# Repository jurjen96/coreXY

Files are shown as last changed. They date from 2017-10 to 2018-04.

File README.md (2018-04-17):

# Introduction

This repository will describe the process of designing and building an open
source 3D printer designed in Autodesk Inventor 2018. I am aware that Autodesk
Inventor is not open source, but when the first version is ready, I will put
STEP files in this repo so that everyone can edit the files.

**Some specs:**
 -  Print volume: 210x200x300 mm
 -  Frame size: 390x400x500 mm

# Planning

 -  ~~Design initial 3D design~~
 -  ~~Build the printer~~
 -  Test the printer
 -  Redesign parts and upgrade the printer
 -  Implement a Raspberry Pi
 -  Implement speech recognition, so that the printer can be controlled by voice

# Current status

The printer is put together and is producing already usable results (example
can be found [here](#printResult)). The next step is to redesign the x-carriage
because it is still not easy to attach the belts to it. Also, all the black belts
will be replaced with belts with metal in it to add more rigidity to the printer.

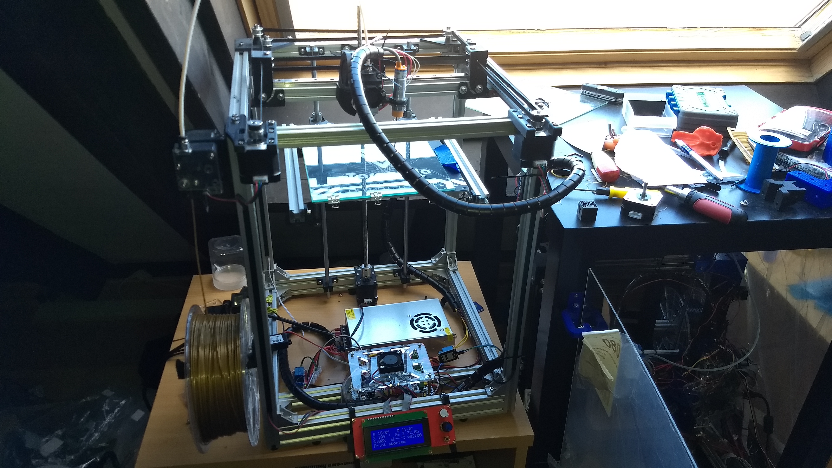
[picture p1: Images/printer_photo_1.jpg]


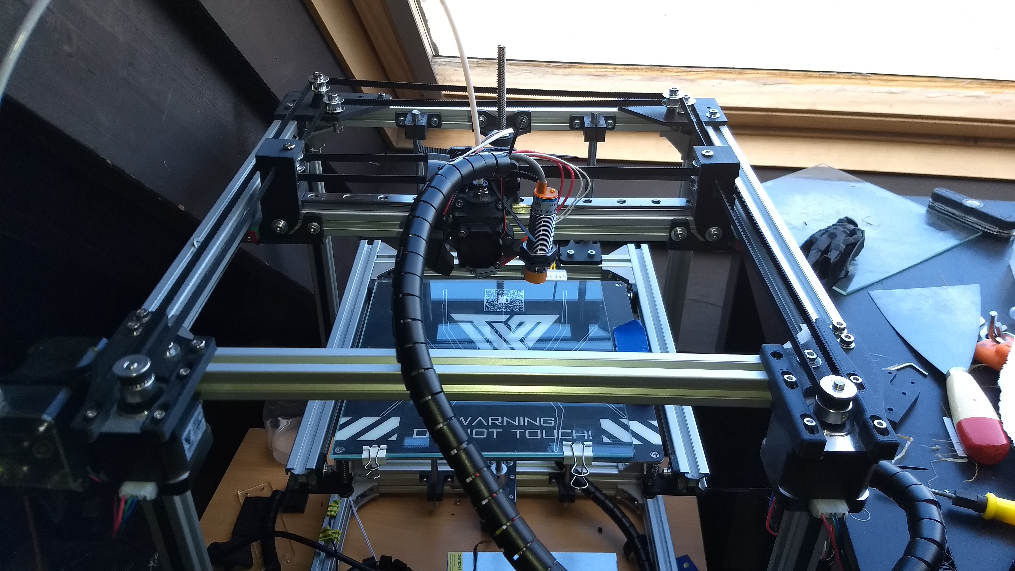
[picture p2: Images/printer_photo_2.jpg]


## Render of design:

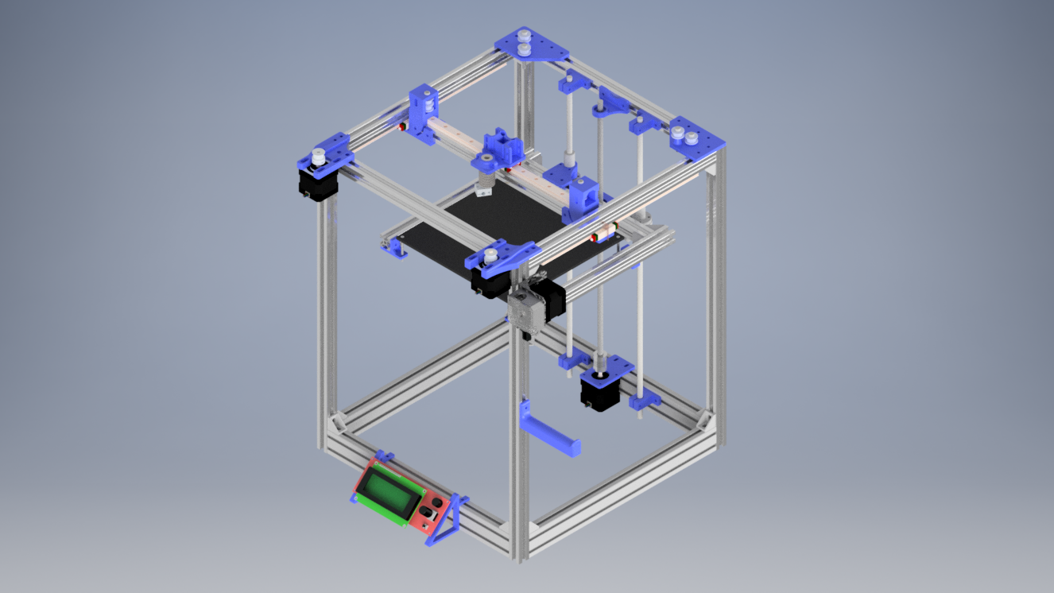
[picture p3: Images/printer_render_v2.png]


##  Print results:

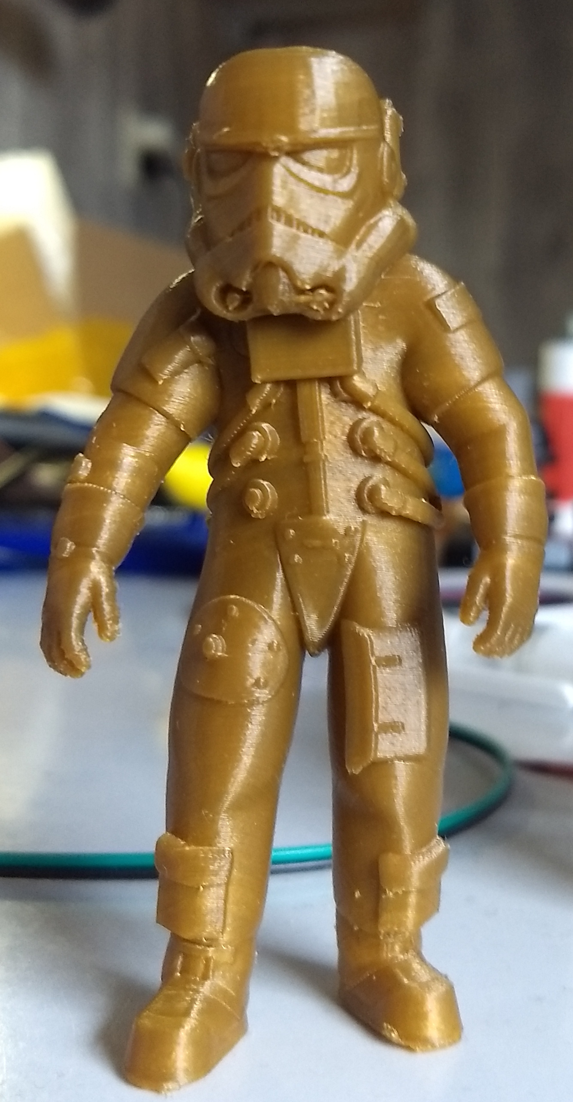
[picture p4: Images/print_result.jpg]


# Credits:

 -  **JuanCR**: [E3DV6 hotend](https://grabcad.com/library/e3dv6-hotend-1-75mm-1 "Grabcad E3DV6")
 -  **Ben Neubauer**: [E3D titan extruder](https://grabcad.com/library/e3d-titan-extruder-2 "Grabcad E3D titan extruder")
 -  **Lehaiver**: [NEMA 17](https://grabcad.com/library/nema-17-40mm-stepper-motor-1 "Grabcad nema 17")
 -  **Tom Edwards**: [Shaft coupler](https://grabcad.com/library/shaft-coupler-5-x-8-x-25mm-1 "Grabcad shaft coupler")
 -  **Jori Mäkinen**: [Linear guide mgn12](https://grabcad.com/library/linear-guide-mgn12-1 "Grabcad linear guide")
 -  **Ryan**: [MGN 12h linear guide](https://grabcad.com/library/hiwin-mgn-12h-linear-guide-1 "Grabcad mgn 12h")
 -  **Paulo Santos**: [GT2 pulley](https://grabcad.com/library/polia-gt2-20-dentes-com-rolamento-gt2-pulley-with-bearing-1 "Grabcad GT2 pulley")
 -  **Motedis**: [2020 extrusion](http://www.motedis.nl/shop/table_cats.php?table_id=16 "Motedis 2020 extrusion")  
 -  **Jacob**: [2004 LCD](https://grabcad.com/library/ramps-2004-lcd-prusa-reprap-screen-1-4-1 "Grabcad 2004 LCD")

This projects makes use of the Marlin firmware which is published under the
GPLv3 license. More information about the Marlin firmware  can be found
[here](http://marlinfw.org/). 

**Notice: This is a work in progress. Use at your own risk!**

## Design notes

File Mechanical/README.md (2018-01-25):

# BOM (**not final**)

Mechanical:
 -  1x E3DV6 (clone)
 -  1x Tevo titan extruder
 -  2020 aluminium extrusion:
    *  4x 500 mm 
    *  4x 350 mm 
    *  6x 320 mm
    *  2x 290 mm
    *  1x 240 mm
 -  2040 aluminium extrusion:
    *  2x 350 mm
 -  1x PTFE tube 1m
 -  1x 430 mm leadscrew
 -  2x 500 mm chrome plated rod
 -  2x LMF8LUU
 -  8x GT2 Idler 20 Teeth Pulley 5 mm bore
 -  2x GT2 20 Teeth Pulley 5mm shaft
 -  1x GT2-6mm Belt 5 m
 -  50x M4 T-nut
 -  1x Borosilicate Glass Plate 213x200x3mm 

Electrical:
 -  4x NEMA17
 -  1x 12v Heat bed 220x220 mm
 -  1x MKS Base v1.4
 -  1x 12V 40w Cartridge heater 
 -  1x NTC 3950 100K ohm 
 -  4x Endstops
 -  1x 12 AWG 1 m RED
 -  1x 12 AWG 1 m BLACK
 -  1x Power supply 220v to 12v

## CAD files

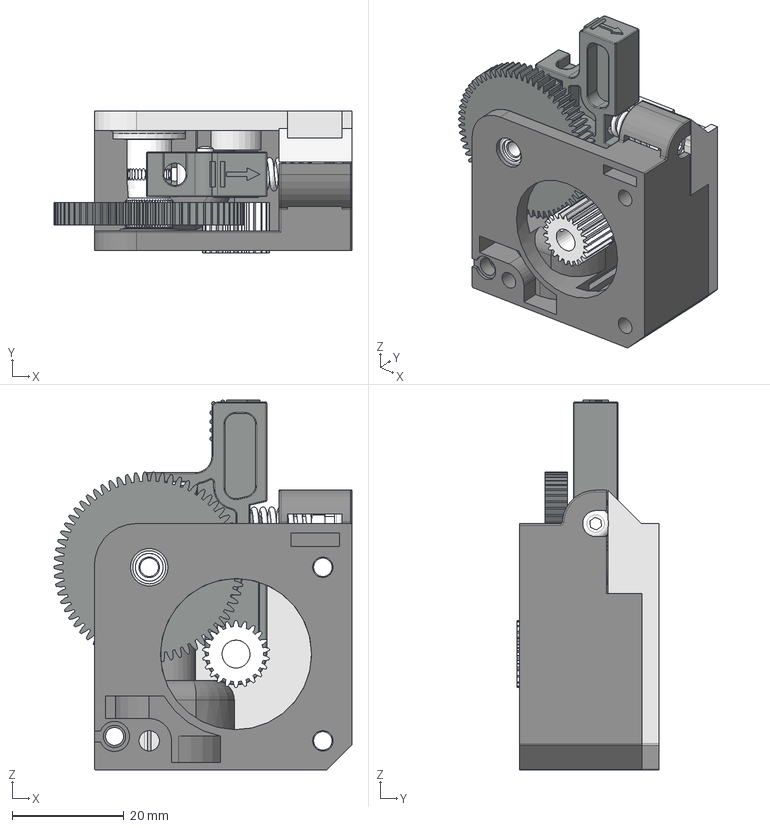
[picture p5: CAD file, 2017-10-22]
Mechanical/extruder/e3d titan.stp
53.2 x 25.3 x 66.1 mm
Base
9x5x3mm bearing x 2
hobbed wheel
filament gear
motor gear
cover
m3x8
M3 nut
idler spring
tensioner
idler bearing pin
idler bearing
guide tube

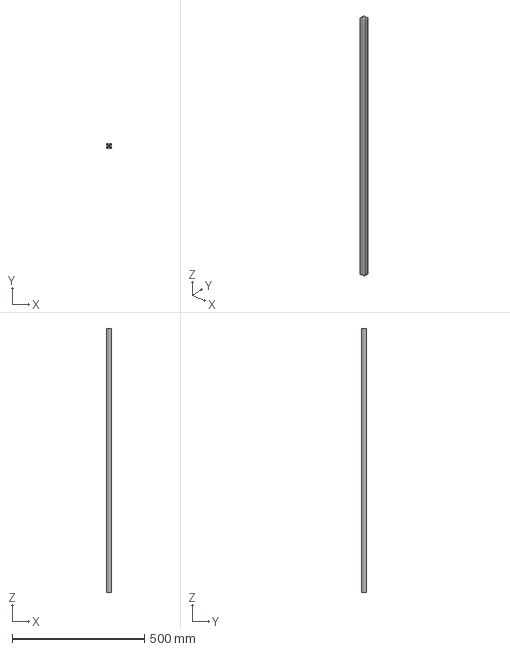
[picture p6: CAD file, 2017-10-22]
Mechanical/motedis/P20_N5_I.stp
20.0 x 20.0 x 1000.0 mm

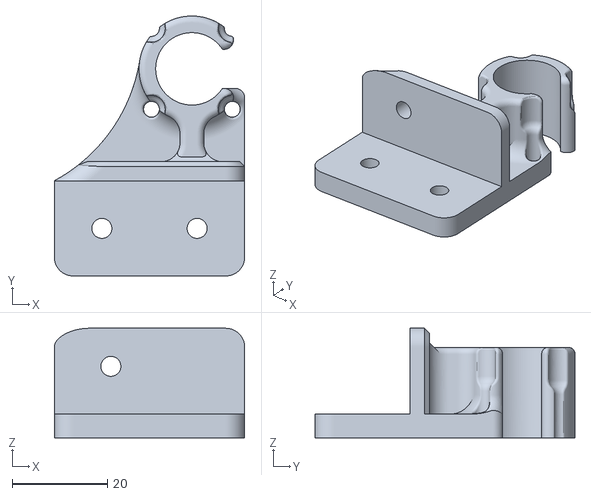
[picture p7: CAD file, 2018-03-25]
Mechanical/Printable Files/reinforcement-z-axis-LMF8LUU.stl
40.0 x 54.6 x 23.0

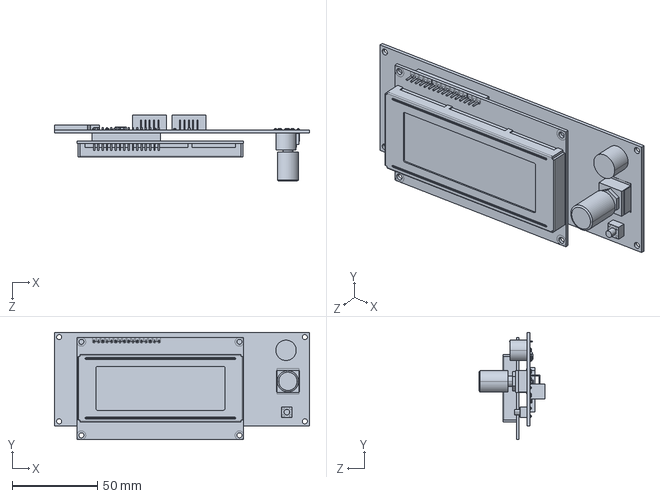
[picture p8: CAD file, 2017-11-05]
Mechanical/Ramps 1.4 2004 LCD PRUSA RepRap.STEP
150.0 x 63.0 x 38.9 mm

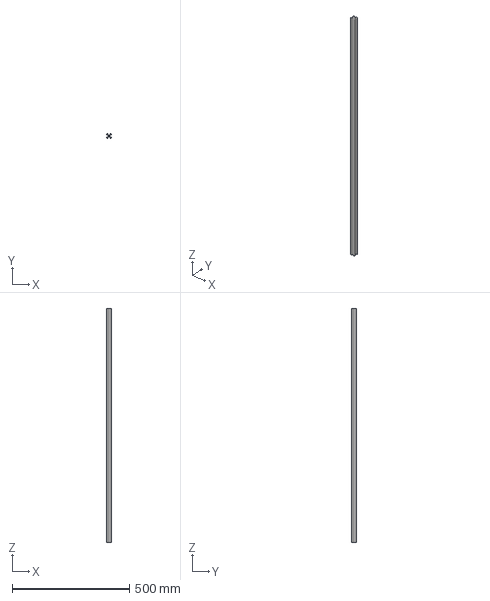
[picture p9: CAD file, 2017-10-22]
Mechanical/motedis/P20_N6_B.stp
20.0 x 20.0 x 1000.0 mm

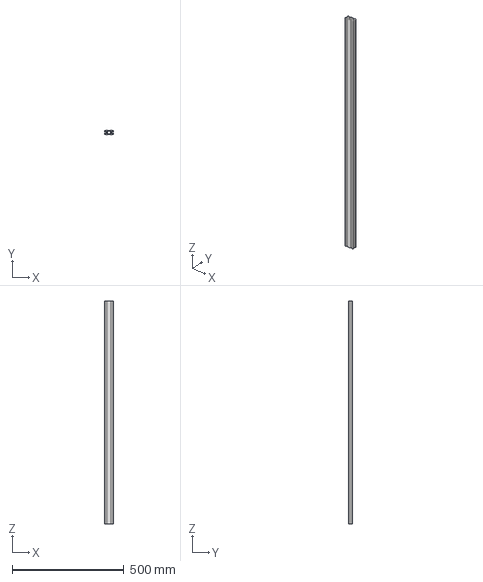
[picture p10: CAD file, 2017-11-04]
Mechanical/P20x40_N5_I.stp
40.0 x 20.0 x 1000.0 mm

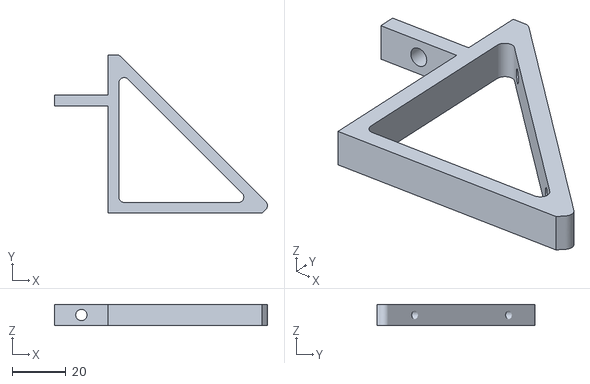
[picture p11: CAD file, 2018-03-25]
Mechanical/Printable Files/holder-LCD-v2.stl
79.3 x 59.0 x 8.00

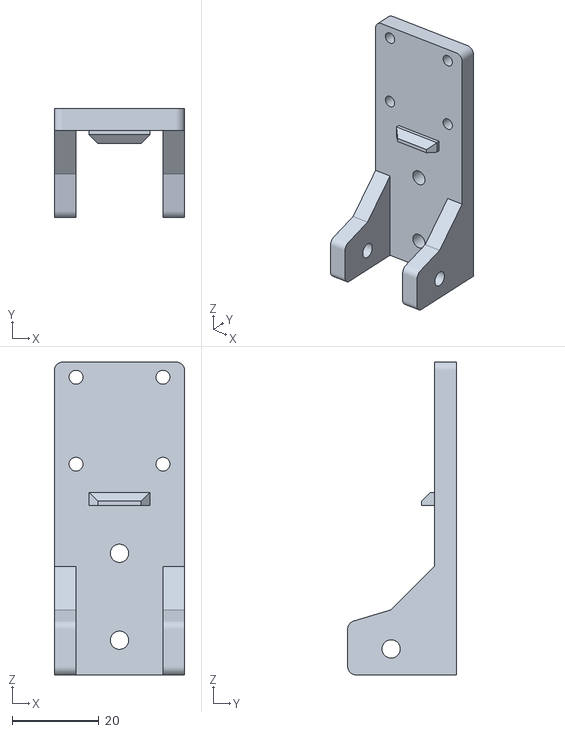
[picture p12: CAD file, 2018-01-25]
Mechanical/Printable Files/X-connector-left.stl
30.0 x 25.0 x 72.0

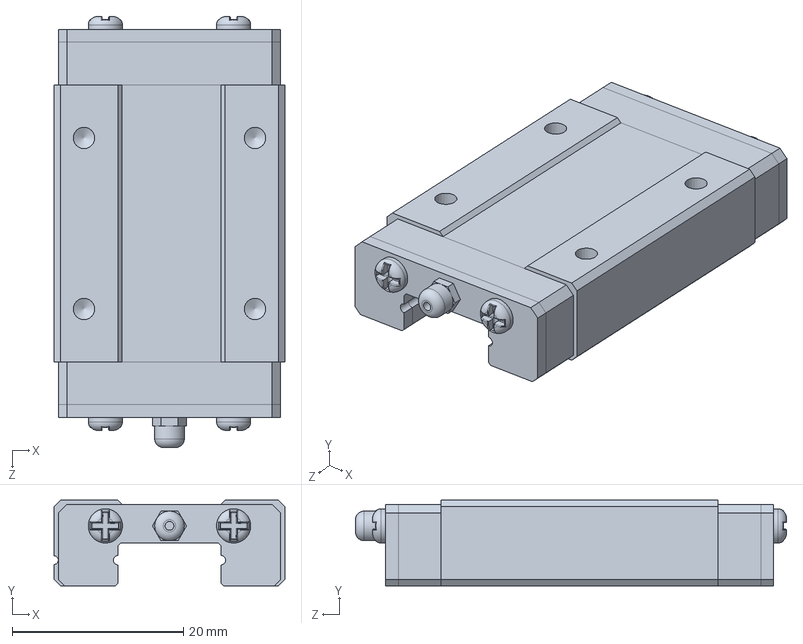
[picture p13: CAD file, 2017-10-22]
Mechanical/MGN_12_H_CARRAGE.SLDPRT
27.0 x 10.0 x 50.4 mm

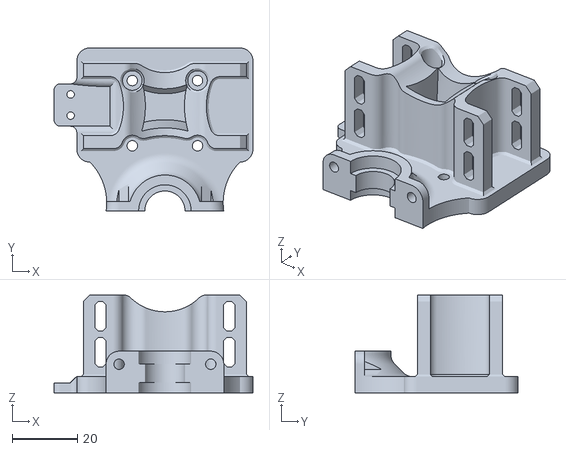
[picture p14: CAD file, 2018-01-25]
Mechanical/Printable Files/x-carriage.stl
61.0 x 50.0 x 30.0

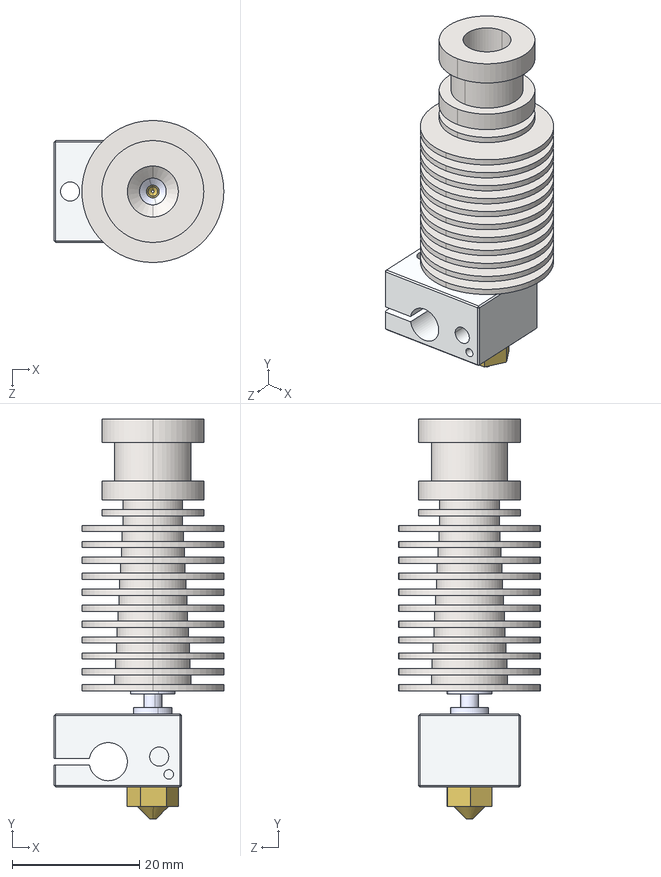
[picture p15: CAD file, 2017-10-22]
Mechanical/ED3V6.STEP
26.7 x 62.8 x 22.3 mm
HEATSINK
NOZZLE 0.4
HEATBRICK
HEATERBLOCK

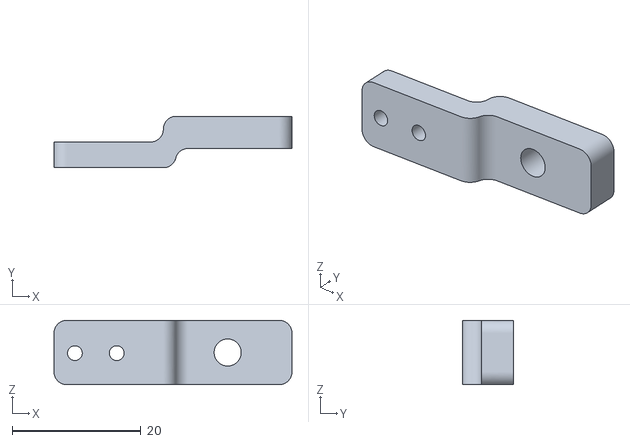
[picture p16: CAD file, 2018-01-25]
Mechanical/Printable Files/y-endstop-bracket.stl
37.0 x 8.00 x 10.0

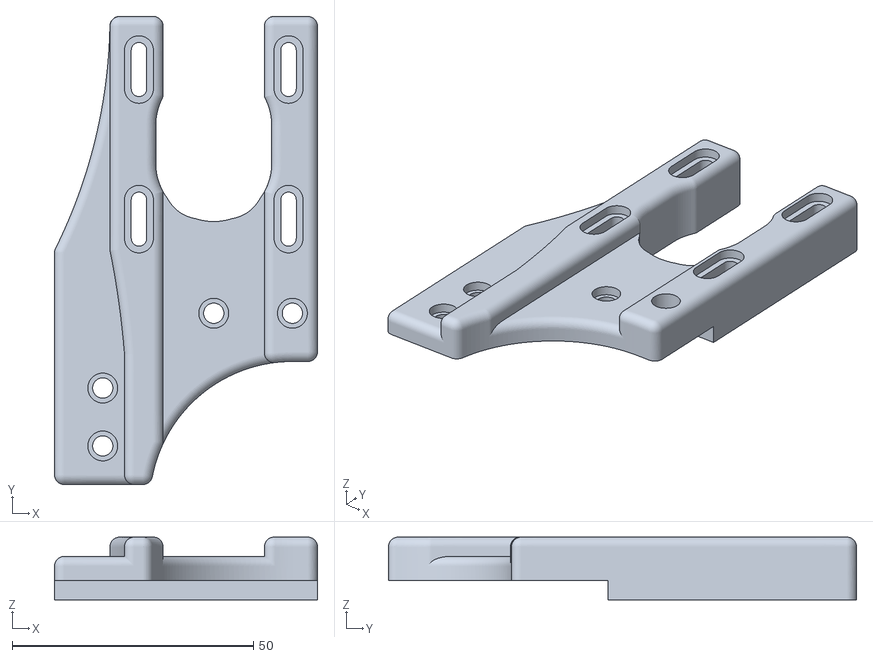
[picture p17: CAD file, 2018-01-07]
Mechanical/Printable Files/nema17-mount-right.stl
54.5 x 97.0 x 13.0

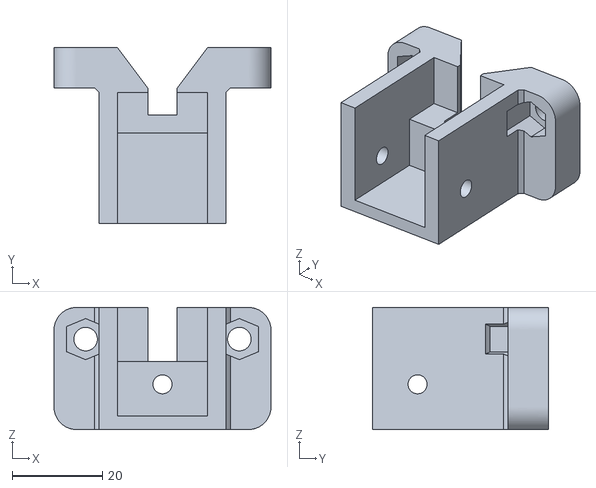
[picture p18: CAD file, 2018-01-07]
Mechanical/Printable Files/holder-GT2-x-carriage-right.stl
48.0 x 39.0 x 27.0

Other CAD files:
Mechanical/Printable Files/X-connector-right.stl
Mechanical/Printable Files/holder-LCD-screen.stl
Mechanical/Printable Files/holder-GT2-x-carriage-left.stl
Mechanical/Printable Files/holder-LMF8LUU-z-axis-v2.stl
Mechanical/00953 - Lineaarijohde MGN 12.SLDPRT
Mechanical/2020-240mm.ipt
Mechanical/2020-260mm.ipt
Mechanical/2020-290mm.ipt
Mechanical/2020-320mm.ipt
Mechanical/2020-350mm.ipt
Mechanical/2020-500mm.ipt
Mechanical/2020-corner-bracket.ipt
Mechanical/2040-350mm.ipt
Mechanical/2040-360mm.ipt
Mechanical/AssemblyFullPrinter.iam
Mechanical/ED3V6.ipt
Mechanical/GT2_Holder.ipt
Mechanical/LMF8LUU.ipt
Mechanical/M3x40mm.ipt
Mechanical/M5-nut.ipt
Mechanical/M5x30mm.ipt
Mechanical/M5x35mm-crosshead.ipt
Mechanical/M5x35mm.ipt
Mechanical/M5x40mm.ipt
Mechanical/MGN-12-H-carriage.ipt
Mechanical/MGN-12-rail.ipt
Mechanical/MotorMount1.ipt
Mechanical/MotorMount1_MIR.ipt
Mechanical/MotorMount2.ipt
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

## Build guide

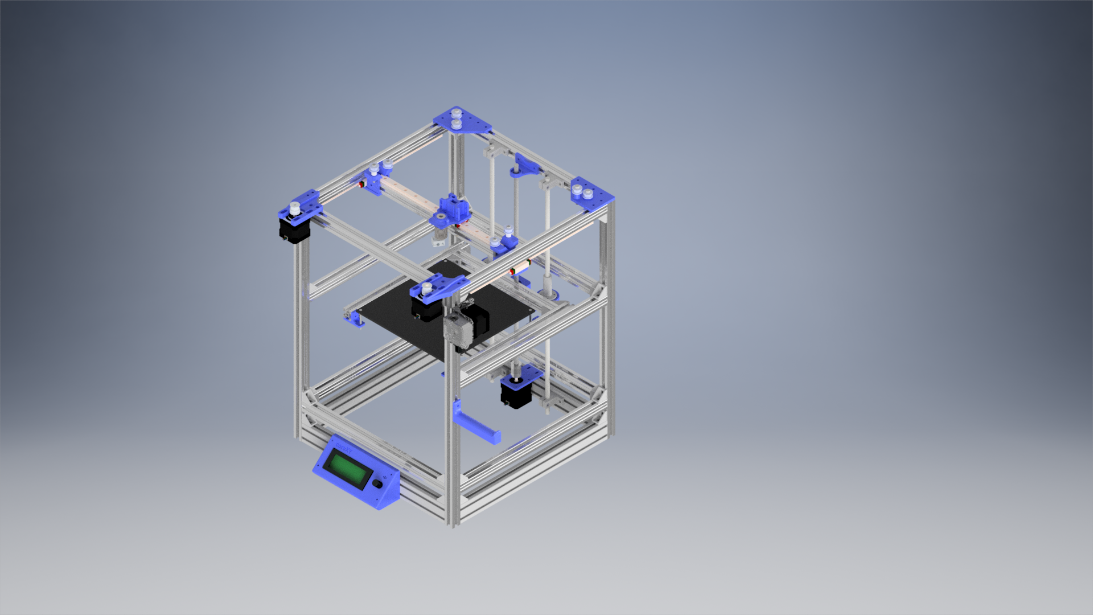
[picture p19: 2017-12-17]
Images/printer_render_v1.png

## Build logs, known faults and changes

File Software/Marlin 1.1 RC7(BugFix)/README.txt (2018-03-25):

This is the Marlin v1.1 Release Candidate Bugfix firmware as of August 9, 2016.

+++++++++++++++++++++++++++++++++++++++++++++++++++++++++++++++++++++++++++++++++++++++++++++++++++++++++++++++++++++
+ IMPORTANT! There are two configuration.h files provided. One with Auto Bed Leveling enabled and one with Auto Bed +
+ Leveling disabled. YOU MUST COPY THE APPROPRIATE CONFIGURATION.H FILE INTO THE MARLIN FOLDER.                     +
+++++++++++++++++++++++++++++++++++++++++++++++++++++++++++++++++++++++++++++++++++++++++++++++++++++++++++++++++++++

Hot end and heated bed PID is enabled, you should run PID autotune.

The configuration.h file with auto bed levelling has been configured for the TEVO Tarantula with a fixed sensor.

This release includes support for multiple extruders. It is not enabled as I can't test this feature.

This release includes support for BLTouch sensor. I don't have one, so can't test. See line 461.

You can now change the LCD controller encoder (knob) direction for menus and for values separately, in configuration.h. See lines 1035 to 1058.

A new feature has been added: Print statistics are now saved. The statistics can be read out with M78 command. (Verbose mode may need to be enabled in your host program.) See lines 930 to 939 in configuration.h

Don't forget to send M502 followed by M500 after uploading to update EEPROM settings!

Use at your own risk!

You will need to modify several settings in configuration.h for your specific printer:

Lines 588 to 591: Set your axis directions. They are currently set to match the build in Ed's videos. Should be fine for most, but some may need to change Y axis direction.

Lines 618 to 624: Set your bed dimensions. (For large bed option, change line 507 to "#define Y_MAX_POS 280")

Lines 731 to 735: Set your home position offsets. See How to set home position offsets below.

Note that EEPROM is enabled. If you do not wish to use EEPROM, comment out line 798.

Lines 489 to 491: If you are using a Z-Probe, set your offsets here. You can leave the Z offset at 0, see comments about M851 below.

If you are using Auto Bed Levelling and you have a fixed sensor attached to the hot end, you should be good to go (after making the changes described above. If you have some other kind of sensor (servo type, sled, etc) read the comments starting at line 441.

Caution! Marlin v1.1 has fixed a glitch in the G92 command. This glitch was used by some to figure out a Z probe offset. It is no longer possible to use G92 to find a Z probe offset. See below for instructions.

Marlin v1.1 has implemented a new custom M code for the Z offset, M851. Syntax is M851 Z<offset> where <offset> is the difference between were the sensor detects the bed and the distance the nozzle is from the bed. It should always be negative for fixed sensor probes. To use follow these steps:

If you are using Repetier-host to control your printer, send M851 Z<same value as Z_MIN_POS> to temporarily set an offset.

Do a G28 to home all axis. 

Do a G1 X100 Y100 to move the nozzle to the middle of the bed.

Place a piece of paper between the nozzle and the bed.

Use your host programs printer controls to lower the Z axis .1 mm at a time.

When you feel some resistance to moving the paper, make a note of the Z position in your host program. (It should be negative. If you are using Repetier-Host, subtract the Z_MIN_POS value you used above.)

Send M851 Z<number> to the printer.

Send M500 to save the offset to EEPROM.

Try a print.

If you need to adjust the Z offset because it is too close or too far away from the bed, simply send another M851 Z<number> with the new offset you want to try, followed by M500. Lather, rinse, repeat until you have the offset dialed in.

Note: due to various environmental factors, the Z offset can change from day to day. If you start a print on a new day and find the Z offset is not right, simply send M851 Z<new offset> followed by M500 until it is good again.

Have fun!
...jim

How to set home position offsets
================================

First, make sure you have the correct bed dimensions defined:

// Travel limits after homing (standard bed)
#define X_MIN_POS 0
#define Y_MIN_POS 0
#define Z_MIN_POS 0
#define X_MAX_POS 200
#define Y_MAX_POS 200
#define Z_MAX_POS 200

(Note: for large bed, use #define Y_MAX_POS 280)

Second, adjust your manual axis home positions:

#define MANUAL_X_HOME_POS 0
#define MANUAL_Y_HOME_POS 0
#define MANUAL_Z_HOME_POS 0

The values for the manual home position depend on the location of your X and Y endstops. To figure out what those values should be, set them to 0 for now, compile and upload the firmware.

Place a mark in the exact center of your bed.

Home your X and Y axis.

Send G1 X100 Y100 (G1 X100 Y140 for large bed) to the printer. This will move the nozzle to what the printer thinks is the center of your bed.

If it is not right above the mark you made, use the jog controls to move the nozzle 1mm at a time until it is as close to being over the mark on the bed as it can.

Note the values of the X and Y axis.

Subtract 100 from those values and change the sign (change positive to negative, negative to positive) and plug them in to the manual axis home position above. (Normally, these should be negative values, if your home direction is min (-1).)

Compile and load the firmware. (Don't forget M502 and M500).

Home X and Y and send G1 X100 Y100 (G1 X100 X140 for large bed).

Your nozzle should now be right over the center mark.

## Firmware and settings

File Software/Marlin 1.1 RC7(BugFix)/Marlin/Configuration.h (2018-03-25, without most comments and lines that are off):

#define CONFIGURATION_H
#define CONFIGURATION_H_VERSION 010100
#define STRING_CONFIG_H_AUTHOR "(Jim Brown, TEVO Tarantula config)" // Who made the changes.
#define SHOW_BOOTSCREEN
#define STRING_SPLASH_LINE1 SHORT_BUILD_VERSION // will be shown during bootup in line 1
#define STRING_SPLASH_LINE2 WEBSITE_URL         // will be shown during bootup in line 2
#define SERIAL_PORT 0
#define BAUDRATE 115200
  #define MOTHERBOARD BOARD_MKS_13
#define CUSTOM_MACHINE_NAME "CoreXY"
#define EXTRUDERS 1
#define POWER_SUPPLY 1
#define TEMP_SENSOR_0 1
#define TEMP_SENSOR_1 0
#define TEMP_SENSOR_2 0
#define TEMP_SENSOR_3 0
#define TEMP_SENSOR_BED 1
#define MAX_REDUNDANT_TEMP_SENSOR_DIFF 10
#define TEMP_RESIDENCY_TIME 5  // (seconds)
#define TEMP_HYSTERESIS 3       // (degC) range of +/- temperatures considered "close" to the target one
#define TEMP_WINDOW     1       // (degC) Window around target to start the residency timer x degC early.
#define TEMP_BED_RESIDENCY_TIME 5  // (seconds)
#define TEMP_BED_HYSTERESIS 3       // (degC) range of +/- temperatures considered "close" to the target one
#define TEMP_BED_WINDOW     1       // (degC) Window around target to start the residency timer x degC early.
#define HEATER_0_MINTEMP 5
#define HEATER_1_MINTEMP 5
#define HEATER_2_MINTEMP 5
#define HEATER_3_MINTEMP 5
#define BED_MINTEMP 5
#define HEATER_0_MAXTEMP 275
#define HEATER_1_MAXTEMP 275
#define HEATER_2_MAXTEMP 275
#define HEATER_3_MAXTEMP 275
#define BED_MAXTEMP 150
#define PIDTEMP
#define BANG_MAX 255 // limits current to nozzle while in bang-bang mode; 255=full current
#define PID_MAX BANG_MAX // limits current to nozzle while PID is active (see PID_FUNCTIONAL_RANGE below); 255=full current
  #define PID_FUNCTIONAL_RANGE 10 // If the temperature difference between the target temperature and the actual temperature
  #define PID_INTEGRAL_DRIVE_MAX PID_MAX  //limit for the integral term
  #define K1 0.95 //smoothing factor within the PID
	#define  DEFAULT_Kp 18.01
	#define  DEFAULT_Ki 1.36
	#define  DEFAULT_Kd 59.77
#define PIDTEMPBED
#define MAX_BED_POWER 255 // limits duty cycle to bed; 255=full current
  #define PID_BED_INTEGRAL_DRIVE_MAX MAX_BED_POWER //limit for the integral term
	#define  DEFAULT_bedKp 322.41
	#define  DEFAULT_bedKi  57.88
	#define  DEFAULT_bedKd 448.99
#define PREVENT_DANGEROUS_EXTRUDE
#define PREVENT_LENGTHY_EXTRUDE
#define EXTRUDE_MINTEMP 170
#define EXTRUDE_MAXLENGTH (X_MAX_LENGTH+Y_MAX_LENGTH) //prevent extrusion of very large distances.
#define THERMAL_PROTECTION_HOTENDS // Enable thermal protection for all extruders
#define THERMAL_PROTECTION_BED     // Enable thermal protection for the heated bed
#define COREXY
#define USE_XMIN_PLUG
#define USE_YMIN_PLUG
#define USE_ZMIN_PLUG
#define ENDSTOPPULLUPS // Comment this out (using // at the start of the line) to disable the endstop pullup resistors
const bool X_MIN_ENDSTOP_INVERTING = true; // set to true to invert the logic of the endstop.
const bool Y_MIN_ENDSTOP_INVERTING = true; // set to true to invert the logic of the endstop.
const bool Z_MIN_ENDSTOP_INVERTING = true; // set to true to invert the logic of the endstop.
const bool X_MAX_ENDSTOP_INVERTING = true; // set to true to invert the logic of the endstop.
const bool Y_MAX_ENDSTOP_INVERTING = true; // set to true to invert the logic of the endstop.
const bool Z_MAX_ENDSTOP_INVERTING = true; // set to true to invert the logic of the endstop.
const bool Z_MIN_PROBE_ENDSTOP_INVERTING = false; // set to true to invert the logic of the endstop.
#define FIX_MOUNTED_PROBE
#define X_PROBE_OFFSET_FROM_EXTRUDER 43  // X offset: -left  +right  [of the nozzle]
#define Y_PROBE_OFFSET_FROM_EXTRUDER 0  // Y offset: -front +behind [the nozzle]
#define Z_PROBE_OFFSET_FROM_EXTRUDER 0   // Z offset: -below +above  [the nozzle]
#define XY_PROBE_SPEED 8000
#define Z_PROBE_SPEED_FAST HOMING_FEEDRATE_Z
#define Z_PROBE_SPEED_SLOW (Z_PROBE_SPEED_FAST / 4)
#define PROBE_DOUBLE_TOUCH
#define Z_MIN_PROBE_USES_Z_MIN_ENDSTOP_PIN
#define Z_MIN_PROBE_REPEATABILITY_TEST
#define Z_PROBE_DEPLOY_HEIGHT 3 // Raise to make room for the probe to deploy / stow
#define Z_PROBE_TRAVEL_HEIGHT 2  // Raise between probing points.
#define Z_PROBE_OFFSET_RANGE_MIN -20
#define Z_PROBE_OFFSET_RANGE_MAX 20
#define X_ENABLE_ON 0
#define Y_ENABLE_ON 0
#define Z_ENABLE_ON 0
#define E_ENABLE_ON 0 // For all extruders
#define DISABLE_X false
#define DISABLE_Y false
#define DISABLE_Z false
#define DISABLE_E false // For all extruders
#define DISABLE_INACTIVE_EXTRUDER true //disable only inactive extruders and keep active extruder enabled
#define INVERT_X_DIR false
#define INVERT_Y_DIR true
#define INVERT_Z_DIR false
#define INVERT_E0_DIR true //false // was false for old extruder
#define INVERT_E1_DIR false
#define INVERT_E2_DIR false
#define INVERT_E3_DIR false
#define X_HOME_DIR -1
#define Y_HOME_DIR -1
#define Z_HOME_DIR -1
#define min_software_endstops true // If true, axis won't move to coordinates less than HOME_POS.
#define max_software_endstops true  // If true, axis won't move to coordinates greater than the defined lengths below.
#define X_MIN_POS 0
#define Y_MIN_POS 0
#define Z_MIN_POS 0
#define X_MAX_POS 200
#define Y_MAX_POS 200
#define Z_MAX_POS 300
#define MESH_BED_LEVELING    // Enable mesh bed leveling.
  #define MESH_INSET 25        // Mesh inset margin on print area
  #define MESH_NUM_X_POINTS 4  // Don't use more than 7 points per axis, implementation limited.
  #define MESH_NUM_Y_POINTS 3
  #define MESH_HOME_SEARCH_Z 4  // Z after Home, bed somewhere below but above 0.0.
  #define MANUAL_BED_LEVELING  // Add display menu option for bed leveling.
    #define MBL_Z_STEP 0.025  // Step size while manually probing Z axis.
#define MANUAL_X_HOME_POS 0
#define MANUAL_Y_HOME_POS 0
#define Z_SAFE_HOMING
  #define Z_SAFE_HOMING_X_POINT 130//((X_MIN_POS + X_MAX_POS) / 2)    // X point for Z homing when homing all axis (G28).
  #define Z_SAFE_HOMING_Y_POINT 165//((Y_MIN_POS + Y_MAX_POS) / 2)    // Y point for Z homing when homing all axis (G28).
#define HOMING_FEEDRATE_XY (50*60)
#define HOMING_FEEDRATE_Z  (4*60)
#define DEFAULT_AXIS_STEPS_PER_UNIT   {80.58,80.58,408.4,416.6}  // custom steps per unit for CoreXY //Eo: 104.5
#define DEFAULT_MAX_FEEDRATE          {225, 225, 3, 25}    // (mm/sec) custom for CoreXY
#define DEFAULT_MAX_ACCELERATION      {1000,1000,100,10000}    // Custom for CoreXY
#define DEFAULT_ACCELERATION          800    // Custom for CoreXY
#define DEFAULT_RETRACT_ACCELERATION  3000    // E acceleration in mm/s^2 for retracts
#define DEFAULT_TRAVEL_ACCELERATION   3000    // X, Y, Z acceleration in mm/s^2 for travel (non printing) moves
#define DEFAULT_XYJERK                10.0    // (mm/sec) Custom for TEVO Tarantula
#define DEFAULT_ZJERK                 0.4     // (mm/sec)
#define DEFAULT_EJERK                 5.0    // (mm/sec)
#define EEPROM_SETTINGS
  #define EEPROM_CHITCHAT // Please keep turned on if you can.
#define DEFAULT_KEEPALIVE_INTERVAL 2  // Number of seconds between "busy" messages. Set with M113.
#define PREHEAT_1_TEMP_HOTEND 190
#define PREHEAT_1_TEMP_BED     50
#define PREHEAT_1_FAN_SPEED     0 // Value from 0 to 255
#define PREHEAT_2_TEMP_HOTEND 240
#define PREHEAT_2_TEMP_BED    100
#define PREHEAT_2_FAN_SPEED     0 // Value from 0 to 255
#define PRINTJOB_TIMER_AUTOSTART
#define PRINTCOUNTER
#define LCD_LANGUAGE en
#define DISPLAY_CHARSET_HD44780 JAPANESE
#define SDSUPPORT
#define ENCODER_PULSES_PER_STEP 1
#define REVERSE_ENCODER_DIRECTION
#define REPRAP_DISCOUNT_SMART_CONTROLLER
#define SOFT_PWM_SCALE 0
#define SERVO_DELAY 300
#define DEFAULT_NOMINAL_FILAMENT_DIA 3.00  //Enter the diameter (in mm) of the filament generally used (3.0 mm or 1.75 mm) - this is then used in the slicer software.  Used for sensor reading validation

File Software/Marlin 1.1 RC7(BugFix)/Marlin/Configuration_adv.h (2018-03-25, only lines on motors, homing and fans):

#define CONTROLLERFAN_PIN -1 //Pin used for the fan to cool controller (-1 to disable)
#define EXTRUDER_0_AUTO_FAN_PIN -1
#define EXTRUDER_1_AUTO_FAN_PIN -1
#define EXTRUDER_2_AUTO_FAN_PIN -1
#define EXTRUDER_3_AUTO_FAN_PIN -1
#define X_HOME_BUMP_MM 5
#define Y_HOME_BUMP_MM 5
#define Z_HOME_BUMP_MM 2
#define HOMING_BUMP_DIVISOR {2, 2, 4}  // Re-Bump Speed Divisor (Divides the Homing Feedrate)
#define MICROSTEP_MODES {16,16,16,16,16} // [1,2,4,8,16]
#define DIGIPOT_MOTOR_CURRENT {135,135,135,135,135} // Values 0-255 (RAMBO 135 = ~0.75A, 185 = ~1A)
#define DIGIPOT_I2C_MOTOR_CURRENTS {1.0, 1.0, 1.0, 1.0, 1.0, 1.0, 1.0, 1.0}
#define LIN_ADVANCE
  #define LIN_ADVANCE_K 0

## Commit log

2017-10-22 Restructured the map structure
    [00953 - Lineaarijohde MGN 12.0002.ipt, 00953 - Lineaarijohde MGN 12.0003.ipt, 00953 - Lineaarijohde MGN 12.SLDPRT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]
2017-10-22 Update regarding the structure of the files
    [00953 - Lineaarijohde MGN 12.0002.ipt, 00953 - Lineaarijohde MGN 12.0003.ipt, 2020-320mm.0001.ipt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]
2017-10-22 Added the current status image
2017-10-29 Update top part printer
    [AssemblyFullPrinter.0046.iam, AssemblyFullPrinter.0054.iam, AssemblyFullPrinter.iam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]
2017-11-04 Update on the z-axis (added holder for lead screw and changed 2020 to 2040 on the back)
    [2020-240mm.0001.ipt, 2020-240mm.0002.ipt, 2020-240mm.ipt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]
2017-11-05 Changed the length of the spool holder
    [spool-holder.0001.ipt, spool-holder.ipt]
2017-11-05 Added an LCD screen and changed the colour of the 3D printed parts
    [2020-320mm.0004.ipt, 2020-320mm.ipt, 2020-500mm.0002.ipt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]
2017-11-05 Added some screws and springs for mounting the bed
    [2020-240mm.0003.ipt, 2020-240mm.ipt, AssemblyFullPrinter.0070.iam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]
2017-12-17 Updated the design based on test prints and added three extra profiles for stability
    [2020-350mm.ipt, 2020-500mm.ipt, 2040-360mm.ipt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]
2018-01-07 Received SH10 instead of the ordered SH8, so I made a printable SH8 version
    [SH8.ipt]
2018-01-07 Made a back up if the linear rail is not good enough using bearing wheels
    [wheel-mount-x-axis.ipt]
2018-01-07 Changed the design of LMF8LUU holder because the original were to weak
    [holder-LMF8LUU-z-axis-v2.ipt]
2018-01-07 Updated most of the parts after testing them, fixed incorrect dimensions
    [2020-240mm.0003.ipt, 2020-240mm.ipt, 2020-350mm.0003.ipt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]
2018-01-21 The original connector did not center the x carriage, the new version does
    [X-connector-left.ipt]
2018-01-25 Updated the README with the current status
2018-01-25 Updated the design and added some new parts. Still need to clean up the design of some parts
    [AssemblyFullPrinter.iam, X-connector-left.stl, X-connector-right.ipt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]
2018-03-25 Added the Marlin code for the 3D printer
    [Configuration.h, Configuration_adv.h]
2018-03-25 Created new LCD holder, the old one used too much filament
    [holder-LCD-v2.ipt, holder-LCD-v2.stl]
2018-03-25 The reinforcement helped a lot to solve issues with a wobling bed
    [reinforcement-z-axis-LMF8LUU.ipt, reinforcement-z-axis-LMF8LUU.stl]
2018-03-25 updated the design of the x carriage
    [x-carriage-v2.ipt]
2018-03-25 Üpdated the assembly
    [AssemblyFullPrinter.iam]
2018-03-25 The old design for the GT2 holder had some flaws
    [holder-GT2-x-carriage-V2-left.ipt, holder-GT2-x-carriage-V2-right.ipt]
2018-04-17 Added credits for Marlin in README

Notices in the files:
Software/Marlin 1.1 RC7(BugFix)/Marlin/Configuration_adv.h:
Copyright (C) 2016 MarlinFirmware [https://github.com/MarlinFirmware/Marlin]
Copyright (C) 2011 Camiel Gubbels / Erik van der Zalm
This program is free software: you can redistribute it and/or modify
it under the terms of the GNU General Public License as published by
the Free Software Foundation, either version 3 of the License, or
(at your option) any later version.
